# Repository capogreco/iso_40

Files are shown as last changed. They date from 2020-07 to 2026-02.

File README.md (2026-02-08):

# Tender Mending Sender

staggered 40 with ISO enter

say what you mean, do what you love, and fucking send it

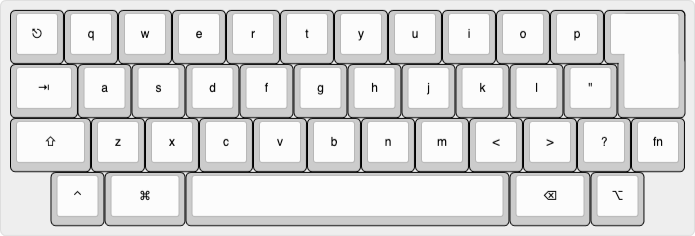
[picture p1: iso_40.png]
iso 40 layout


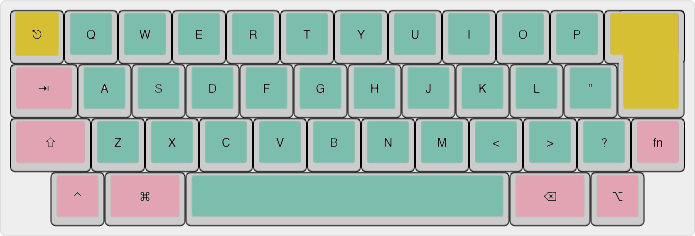
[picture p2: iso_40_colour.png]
iso 40 colour layout


## Layout

40-key staggered keyboard with ISO Enter, 6u spacebar, and ATmega32U4.

### Layer 0 — Default

| | | | | | | | | | | | |
|---|---|---|---|---|---|---|---|---|---|---|---|
| Esc | Q | W | E | R | T | Y | U | I | O | P | Enter (ISO) |
| Tab/Ctrl | A | S | D | F | G | H | J | K | L | ' | |
| Shift | Z | X | C | V | B | N | M | , | . | / | Fn2 |
| | Fn1 | Super | | | Space (6u) | | | | Bksp | AltGr | |

### Layer 1 — Numbers / Punctuation (Fn1)

| | | | | | | | | | | | |
|---|---|---|---|---|---|---|---|---|---|---|---|
| | | | | | | | 7 | 8 | 9 | 0 | |
| | \` | \\ | [ | ] | - | = | 4 | 5 | 6 | ; | |
| | | | | | , | . | 1 | 2 | 3 | | |
| | | | | | | | | | | | |

### Layer 2 — Navigation / Function (Fn2)

| | | | | | | | | | | | |
|---|---|---|---|---|---|---|---|---|---|---|---|
| | F1 | F2 | F3 | F4 | Vol+ | | | | | PrtScn | |
| | F5 | F6 | F7 | F8 | Vol- | | PgUp | Home | Up | End | |
| | F9 | F10 | F11 | F12 | Mute | | PgDn | Left | Down | Right | |
| | | | | | | | | | Del | | |

## Firmware

QMK firmware source is in `iso_40/`. To compile and flash:

```
qmk compile -kb iso_40 -km default
qmk flash -kb iso_40 -km default
```

Requires `avr-gcc`, `avrdude`, and the QMK CLI. The keyboard directory needs to be copied into your `qmk_firmware/keyboards/` tree before compiling.

Bootloader is Caterina (Pro Micro compatible) — double-tap reset to enter bootloader mode.

## PCB

Designed in KiCad. Gerber files for manufacturing are in `gerbers/`.

Switch footprints from [ai03 MX_Alps_Hybrid](https://github.com/ai03-2725/MX_Alps_Hybrid) and [random-keyboard-parts](https://github.com/ai03-2725/random-keyboard-parts.pretty) (included as git submodules).

## License

[MIT](LICENSE)

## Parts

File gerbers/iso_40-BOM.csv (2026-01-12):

Comment | Designator | Footprint | LCSC Part #
1N4148W | D1,D2,D3,D4,D5,D6,D7,D8,D9,D10,D11,D12,D13,D14,D15,D16,D17,D18,D19,D20,D21,D22,D23,D24,D25,D26,D27,D28,D29,D30,D31,D32,D33,D34,D35,D36,D37,D38,D39,D40 | D_SOD-123 | C84367
22pF | C1,C2 | C_0805_2012Metric | C1804
1uF | C3,C4,C5,C6,C7 | C_0805_2012Metric | C28323
500mA | F1 | Fuse_1206_3216Metric | C70074
10k | R1,R4 | R_0805_2012Metric | C17414
22 | R2,R3 | R_0805_2012Metric | C17520
SKQGABE010 | SW1 | SKQG-1155865 | C115351
ATmega32U4-AU | U1 | TQFP-44_10x10mm_P0.8mm | C44854
16MHz | Y1 | Crystal_SMD_3225-4Pin_3.2x2.5mm | C13738
AVR-ISP-6 | J1 | PinHeader_2x03_P2.54mm_Vertical_SMD | C77761
USB4110-GF-A | J2 | USB_C_Receptacle_GCT_USB4110 | C5143397

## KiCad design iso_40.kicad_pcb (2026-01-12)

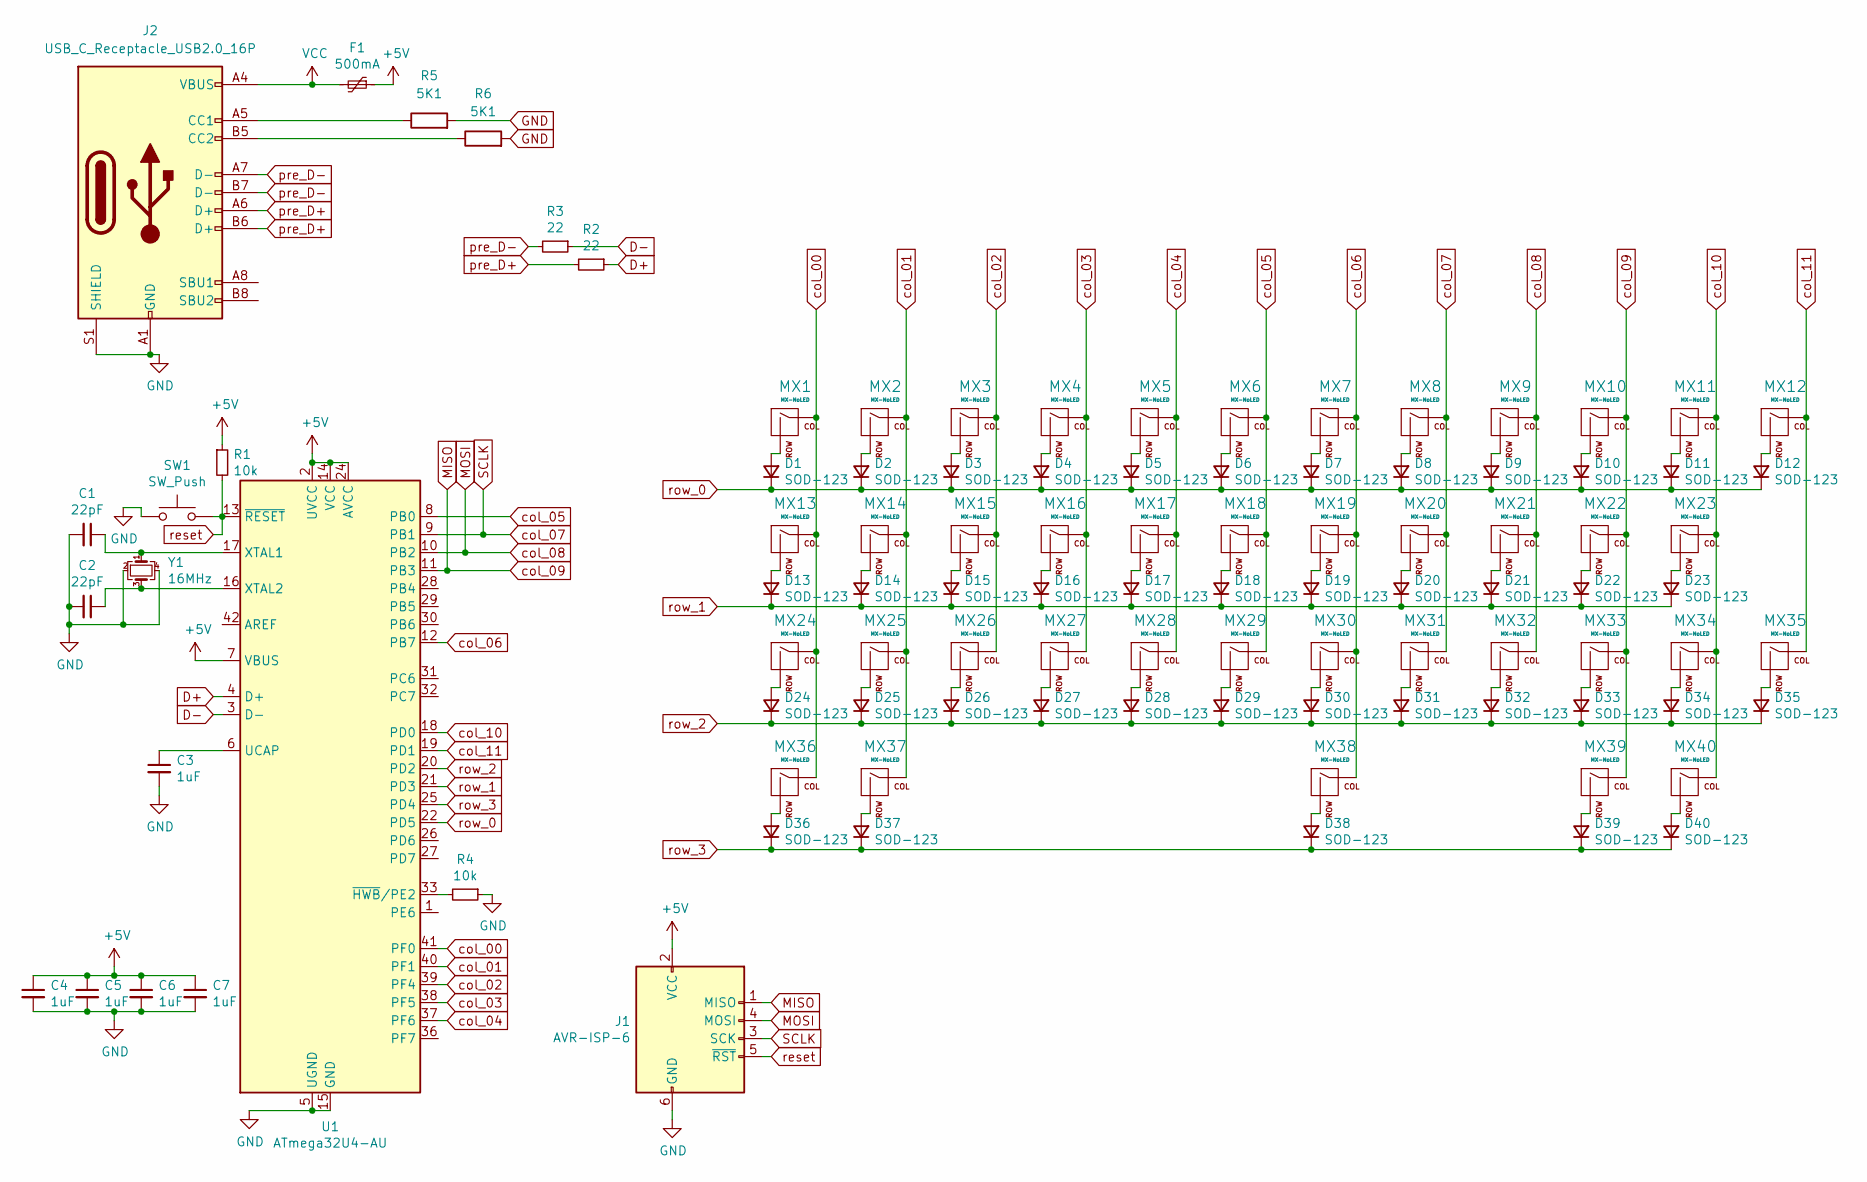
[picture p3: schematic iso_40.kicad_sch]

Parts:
C1, C2: 22pF; C_0805_2012Metric
C3, C4, C5, C6, C7: 1uF; C_0805_2012Metric
D1, D2, D3, D4, D5, D6, D7, D8, D9, D10, D11, D12, D13, D14, D15, D16, D17, D18, D19, D20, D21, D22, D23, D24, D25, D26, D27, D28, D29, D30, D31, D32, D33, D34, D35, D36, D37, D38, D39, D40: SOD-123; D_SOD-123
F1: 500mA; Fuse_1206_3216Metric
J1: AVR-ISP-6; PinHeader_2x03_P1.27mm_Vertical_SMD
J2: USB_C_Receptacle_USB2.0_16P; USB_C_Receptacle_GCT_USB4110
MX1, MX2, MX3, MX4, MX5, MX6, MX7, MX8, MX9, MX10, MX11, MX14, MX15, MX16, MX17, MX18, MX19, MX20, MX21, MX22, MX23, MX25, MX26, MX27, MX28, MX29, MX30, MX31, MX32, MX33, MX34, MX35, MX36, MX40: MX-NoLED; MXOnly-1U-NoLED
MX12: MX-NoLED; MXOnly-ISO
MX13: MX-NoLED; MXOnly-1.25U-NoLED
MX24, MX37, MX39: MX-NoLED; MXOnly-1.5U-NoLED
MX38: MX-NoLED; MXOnly-6U-NoLED
R1, R4: 10k; R_0805_2012Metric
R2, R3: 22; R_0805_2012Metric
R5, R6: 5K1
SW1: SW_Push; SKQG-1155865
U1: ATmega32U4-AU; TQFP-44_10x10mm_P0.8mm
Y1: 16MHz; Crystal_SMD_3225-4Pin_3.2x2.5mm

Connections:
+5V: C4.1, C5.1, C6.1, C7.1, F1.1, J1.2 (VCC), R1.1, U1.2 (UVCC), U1.7 (VBUS), U1.14 (VCC), U1.24 (AVCC), U1.34 (VCC), U1.44 (AVCC)
D+: R2.1, U1.4 (D+)
D-: R3.1, U1.3 (D-)
GND: C1.2, C2.2, C3.2, C4.2, C5.2, C6.2, C7.2, J1.6 (GND), J2.A1 (GND), J2.A12 (GND), J2.B1 (GND), J2.B12 (GND), J2.S1 (SHIELD), R4.1, SW1.1, U1.5 (UGND), U1.15 (GND), U1.23 (GND), U1.35 (GND), U1.43 (GND), Y1.2, Y1.4
MISO: J1.1 (MISO), MX10.1 (COL), MX22.1 (COL), MX33.1 (COL), MX39.1 (COL), U1.11 (PB3)
MOSI: J1.4 (MOSI), MX9.1 (COL), MX21.1 (COL), MX32.1 (COL), U1.10 (PB2)
unnamed: D1.2 (A), MX1.2 (ROW)
unnamed: D2.2 (A), MX2.2 (ROW)
unnamed: D3.2 (A), MX3.2 (ROW)
unnamed: D4.2 (A), MX4.2 (ROW)
unnamed: D5.2 (A), MX5.2 (ROW)
unnamed: D6.2 (A), MX6.2 (ROW)
unnamed: D7.2 (A), MX7.2 (ROW)
unnamed: D8.2 (A), MX8.2 (ROW)
unnamed: D9.2 (A), MX9.2 (ROW)
unnamed: D10.2 (A), MX10.2 (ROW)
unnamed: D11.2 (A), MX11.2 (ROW)
unnamed: D12.2 (A), MX12.2 (ROW)
unnamed: D13.2 (A), MX13.2 (ROW)
unnamed: D14.2 (A), MX14.2 (ROW)
unnamed: D15.2 (A), MX15.2 (ROW)
unnamed: D16.2 (A), MX16.2 (ROW)
unnamed: D17.2 (A), MX17.2 (ROW)
unnamed: D18.2 (A), MX18.2 (ROW)
unnamed: D19.2 (A), MX19.2 (ROW)
unnamed: D20.2 (A), MX20.2 (ROW)
unnamed: D21.2 (A), MX21.2 (ROW)
unnamed: D22.2 (A), MX22.2 (ROW)
unnamed: D23.2 (A), MX23.2 (ROW)
unnamed: D24.2 (A), MX24.2 (ROW)
unnamed: D25.2 (A), MX25.2 (ROW)
unnamed: D26.2 (A), MX26.2 (ROW)
unnamed: D27.2 (A), MX27.2 (ROW)
unnamed: D28.2 (A), MX28.2 (ROW)
unnamed: D29.2 (A), MX29.2 (ROW)
unnamed: D30.2 (A), MX30.2 (ROW)
unnamed: D31.2 (A), MX31.2 (ROW)
unnamed: D32.2 (A), MX32.2 (ROW)
unnamed: D33.2 (A), MX33.2 (ROW)
unnamed: D34.2 (A), MX34.2 (ROW)
unnamed: D35.2 (A), MX35.2 (ROW)
unnamed: D36.2 (A), MX36.2 (ROW)
unnamed: D37.2 (A), MX37.2 (ROW)
unnamed: D38.2 (A), MX38.2 (ROW)
unnamed: D39.2 (A), MX39.2 (ROW)
unnamed: D40.2 (A), MX40.2 (ROW)
unnamed: J2.A5 (CC1), R5.1
unnamed: J2.B5 (CC2), R6.1
unnamed: R5.2, R6.2
unnamed: C3.1, U1.6 (UCAP)
unnamed: C1.1, U1.17 (XTAL1), Y1.1
unnamed: C2.1, U1.16 (XTAL2), Y1.3
unnamed: R4.2, U1.33 (~HWB/PE2)
SCLK: J1.3 (SCK), MX8.1 (COL), MX20.1 (COL), MX31.1 (COL), U1.9 (PB1)
VCC: F1.2, J2.A4 (VBUS), J2.A9 (VBUS), J2.B4 (VBUS), J2.B9 (VBUS)
col_00: MX1.1 (COL), MX13.1 (COL), MX24.1 (COL), MX36.1 (COL), U1.41 (PF0)
col_01: MX2.1 (COL), MX14.1 (COL), MX25.1 (COL), MX37.1 (COL), U1.40 (PF1)
col_02: MX3.1 (COL), MX15.1 (COL), MX26.1 (COL), U1.39 (PF4)
col_03: MX4.1 (COL), MX16.1 (COL), MX27.1 (COL), U1.38 (PF5)
col_04: MX5.1 (COL), MX17.1 (COL), MX28.1 (COL), U1.37 (PF6)
col_05: MX6.1 (COL), MX18.1 (COL), MX29.1 (COL), U1.8 (PB0)
col_06: MX7.1 (COL), MX19.1 (COL), MX30.1 (COL), MX38.1 (COL), U1.12 (PB7)
col_10: MX11.1 (COL), MX23.1 (COL), MX34.1 (COL), MX40.1 (COL), U1.18 (PD0)
col_11: MX12.1 (COL), MX35.1 (COL), U1.19 (PD1)
pre_D+: J2.A6 (D+), J2.B6 (D+), R2.2
pre_D-: J2.A7 (D-), J2.B7 (D-), R3.2
reset: J1.5 (~RST), R1.2, SW1.2, U1.13 (~RESET)
row_0: D1.1 (K), D2.1 (K), D3.1 (K), D4.1 (K), D5.1 (K), D6.1 (K), D7.1 (K), D8.1 (K), D9.1 (K), D10.1 (K), D11.1 (K), D12.1 (K), U1.22 (PD5)
row_1: D13.1 (K), D14.1 (K), D15.1 (K), D16.1 (K), D17.1 (K), D18.1 (K), D19.1 (K), D20.1 (K), D21.1 (K), D22.1 (K), D23.1 (K), U1.21 (PD3)
row_2: D24.1 (K), D25.1 (K), D26.1 (K), D27.1 (K), D28.1 (K), D29.1 (K), D30.1 (K), D31.1 (K), D32.1 (K), D33.1 (K), D34.1 (K), D35.1 (K), U1.20 (PD2)
row_3: D36.1 (K), D37.1 (K), D38.1 (K), D39.1 (K), D40.1 (K), U1.25 (PD4)

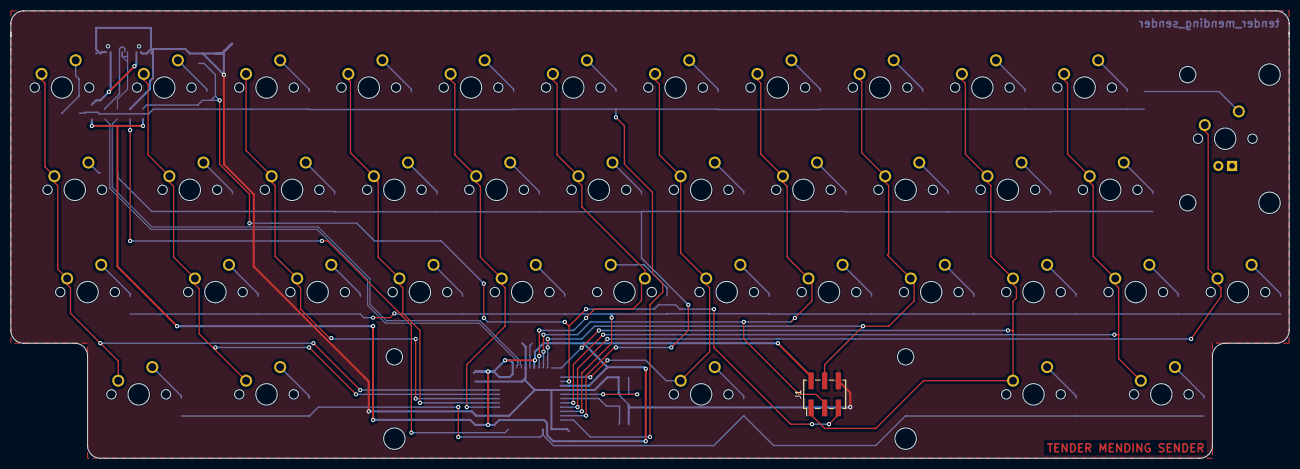
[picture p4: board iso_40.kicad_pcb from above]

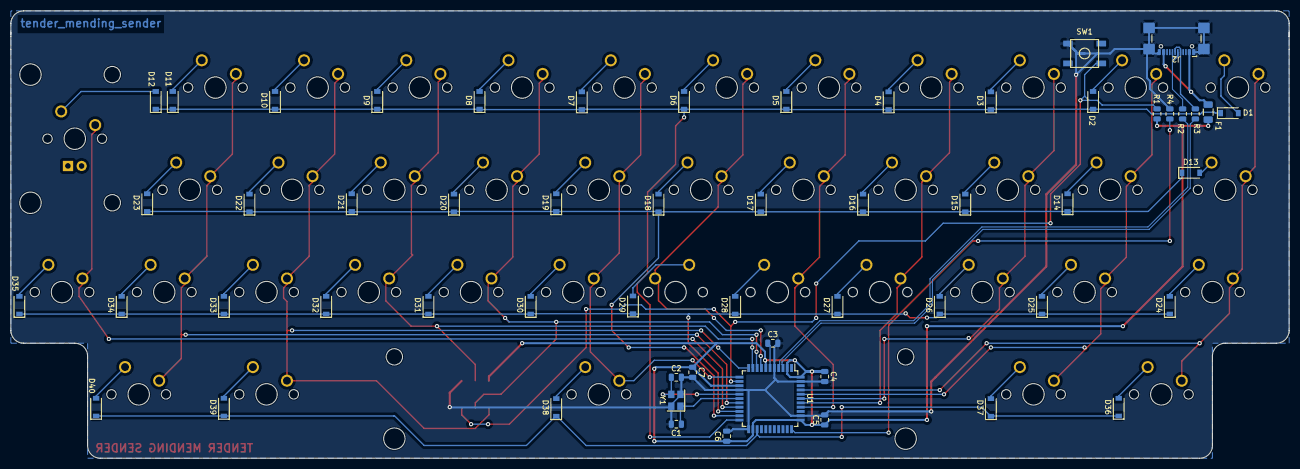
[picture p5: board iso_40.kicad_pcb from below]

Board: 2 copper layers, 238.1 x 83.3 mm, 97 parts (57 on the bottom side), 68 nets.

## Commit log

2020-07-19 component and footprint libraries
2020-07-19 layout png
    [iso_40.sch]
2020-07-21 pcb routed
    [iso_40.sch]
2020-07-26 ISP header added
    [iso_40.kicad_pcb, iso_40.sch]
2026-01-12 pcb changes, etc
    [iso_40-BOM.csv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]
2026-01-12 Add .gitignore and remove unneeded files from tracking
    - Ignore KiCad backup files, lock files, and autosave files
    - Ignore fp-info-cache (can be regenerated)
    - Ignore macOS .DS_Store files
2026-02-08 Add PrtScn, Delete, AltGr to keymap; clean up repo
    - Add KC_PSCR to Layer 2 (Fn2+P) for screenshots
    - Add KC_DEL to Layer 2 (Fn2+Bksp) for forward delete
    - Change bottom-right from KC_LALT to KC_RALT (AltGr)
    - Remove obsolete KiCad 5 files, backups, generated exports,
    and unrelated phone_concept directory
    - Update .gitignore for KiCad artifacts and QMK build output
    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
    [iso_40.sch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]
